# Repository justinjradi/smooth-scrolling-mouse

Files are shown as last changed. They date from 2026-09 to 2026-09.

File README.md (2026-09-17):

# Smooth Scrolling Mouse

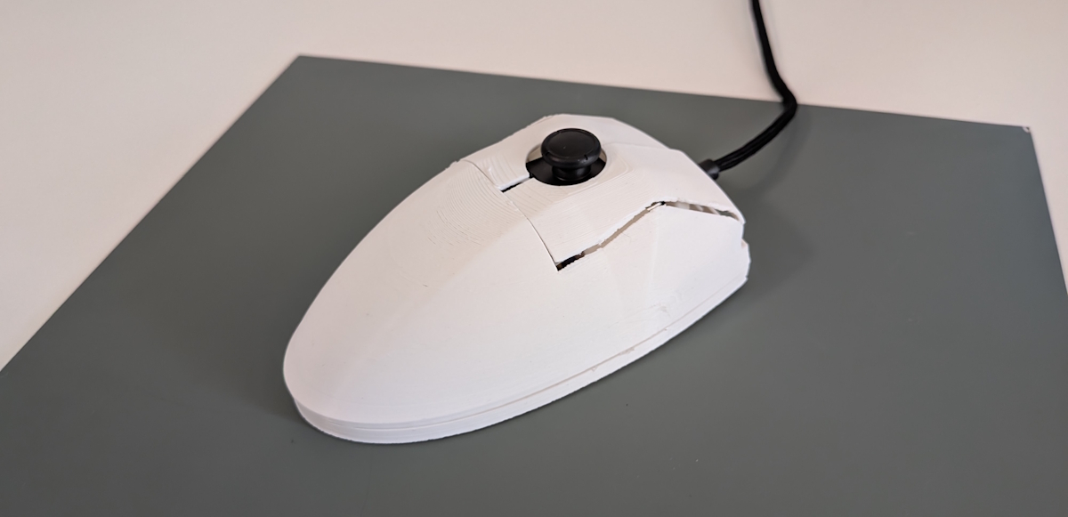
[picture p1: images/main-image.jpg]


### Overview

In this project, I built a a new type of USB computer mouse capable of scrolling and panning smoothly in any direction. The scroll wheel is replaced with a finger-operated joystick, which is held static during usage instead of being constantly when navigating large documents and workspaces.

Firmware was developed for a STM32 development board, involving writing custom USB device applications, a driver for a PMW3610 optical sensor, and reverse-engineering the requirements of Windows hosts using protocol knowledge and Wireshark. Furthermore, a chassis with clicking mechanism was designed using Autodesk Fusion and fabricated using an FDM 3D printer.

### System Design

The system was designed using a [WeAct STM32F411CEU6 development board](https://stm32-base.org/boards/STM32F411CEU6-WeAct-Black-Pill-V2.0.html), chosen for its small size, user USB connector, and USB FS peripheral supported by TinyUSB. A simple breakout board-based system architecture was used given that this was a quick prototype without large SI constraints.

The MCU development board was soldered onto perfboard along with Kailh silent mouse switches, pull-down resistors, and pin headers to form a mainboard. A PMW3610-DM optical mouse sensor breakout board was used for cursor tracking. Lastly, scrolling was implemented using a joystick.

A replacement joystick for the Nintendo switch and which was chosen to control scrolling/panning because of its small size, low force required to displace, and built-in button. Additionally, an FPC connector breakout board was used to interface with it.

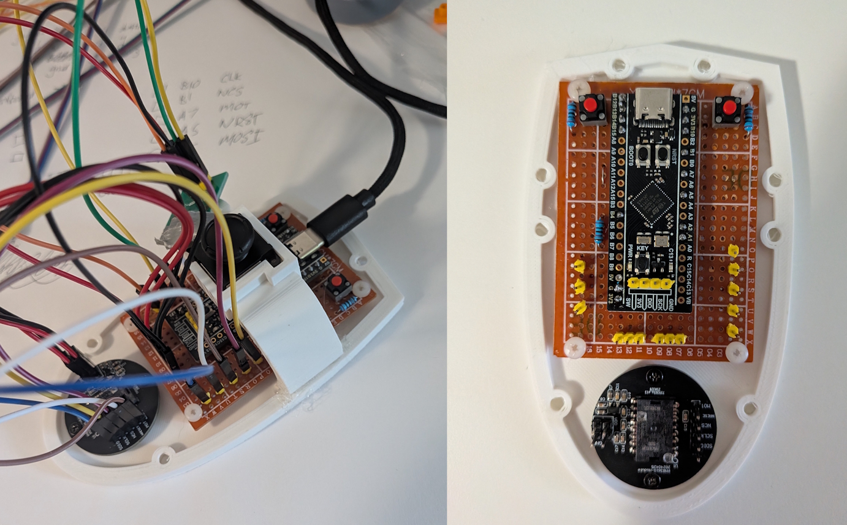
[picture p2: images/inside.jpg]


### Firmware Development

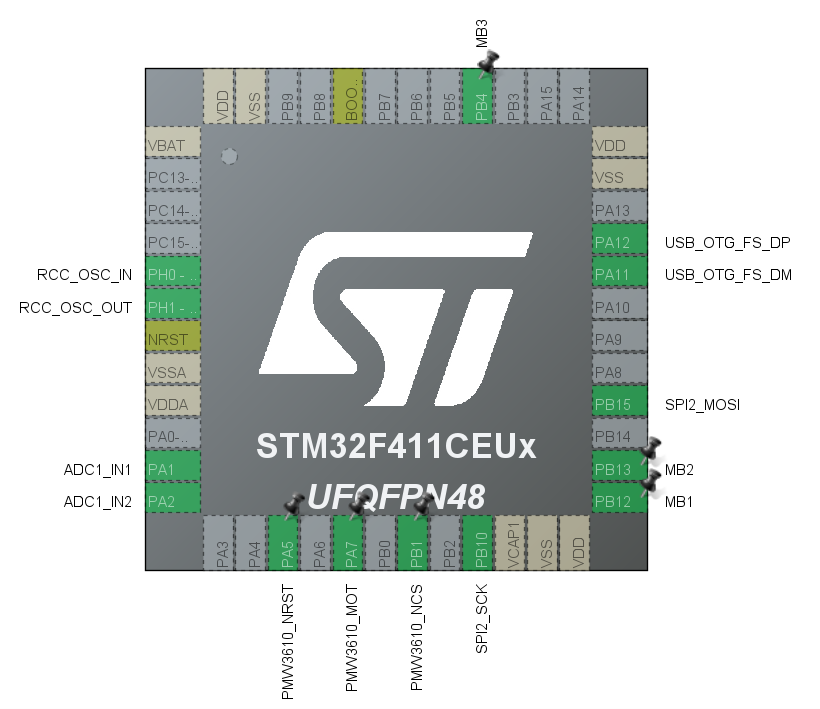
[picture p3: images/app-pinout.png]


#### Main Program

The main loop is structured as a single non-blocking cycle with one deliberate blocking point: a fixed 10-ms minimum loop time enforced right before the report is sent, which keeps the report rate steady regardless of how long sensor polling and other input handling take. At the top of every iteration, a timestamp is taken and the report's `x` and `y` fields are cleared, since these are relative values that should default to zero unless new motion is detected that iteration (unlike the buttons, which reflect a continuous state).

Pseudocode of the main program loop follows:

```pseudocode
loop:
    timestamp = now()
    report.x = 0
    report.y = 0

    tud_task()                      // service USB stack

    if MOT_pin is asserted:
        read burst motion data from PMW3610
        if valid:
            report.x = convert(delta_x)
            report.y = convert(delta_y)

    report.left_button   = !MB1_pin
    report.right_button  = !MB2_pin
    report.middle_button = !MB3_pin

    start ADC conversion (channel 1)
    report.scroll = convert(adc_value)

    start ADC conversion (channel 2)
    report.pan = convert(adc_value)
    stop ADC

    wait until (now() - timestamp) >= 10ms
    send report
```

The optical sensor is polled and the `MOT` pin is just read as a plain GPIO input each iteration. Updates to mouse buttons, however, are implemented using interrupts.

The joystick's two axes go through ADC1, configured for two channels in discontinuous conversion mode with a single conversion per trigger (`NbrOfDiscConversion = 1`). Rather than firing off both channels back-to-back in scan mode, each `HAL_ADC_Start()`/`HAL_ADC_PollForConversion()` call advances the sequencer by exactly one channel, so the two axes can be read as two distinct, independently-timed conversions within the loop. No DMA is used as polling was sufficiently fast at this conversion rate.

With respect to clock configuration, SYSCLK is set to 16 MHz and PLL M/N/Q dividers were chosen to provide exactly 48 MHz to the USB OTG peripheral.

#### PMW3610 Driver

A driver for the PMW3610 optical sensor is implemented in `inc/pmw3610.h`. The PMW3610 communicates over a 3-wire SPI-like interface, so SPI2 is configured half-duplex, `SPI_DIRECTION_1LINE`, meaning MOSI and MISO share a single physical line and the peripheral is manually switched between transmit and receive around each register access. It's set to Mode 0 (`CLKPolarity = LOW`, `CLKPhase = 1EDGE`) and a baud rate of 31.25 kbit. For simplicity, chip-select is implemented with GPIO calls.

Every register access follows the same two-phase pattern: select the chip, send a one-byte header with the MSB indicating read (0) or write (1) and the lower 7 bits as the register address, then either transmit or receive the data byte(s), and deselect. A read looks like this:

```c
HAL_GPIO_WritePin(dev_p->NCS_port_p, dev_p->NCS_pin, NCS_SELECT);

uint8_t first_byte[1] = {address & 0b01111111};  // MSB = 0: read operation
result = HAL_SPI_Transmit(dev_p->hspi_p, first_byte, 1, SPI_DEFAULT_TIMEOUT);

result = HAL_SPI_Receive(dev_p->hspi_p, data_p, size, SPI_DEFAULT_TIMEOUT);

HAL_GPIO_WritePin(dev_p->NCS_port_p, dev_p->NCS_pin, NCS_DESELECT);
```

Writes follow a similar process, sending the address with the MSB set to 1 followed by the value byte. `write_reg()` additionally wraps this in a clock-enable/disable sequence (writing specific values to the sensor's clock control register before and after) since the datasheet requires the sensor's internal SPI clock to be explicitly turned on before a write and off afterward.

`pmw3610_init()` runs through the sensor's documented startup sequence: power the sensor up from shutdown, clear the observation register, then read it back and check that the lower four bits read `1111` as the datasheet specifies (this confirms the sensor booted correctly). It then reads the product ID register and checks it against the expected value for the PMW3610, and finally writes a small set of performance/downshift registers to their recommended initial values.

`pmw3610_get_values()` does a single 4-byte burst read starting at the burst register, which returns the motion status byte plus the low bytes of X and Y and a shared high-nibble byte. If the motion bit isn't set, there's no new data and the function returns early with `valid = PMW3610_MOT_REG_INVAL`. Otherwise, the delta values need to be reconstructed: X and Y are each 12-bit signed integers, but the sensor packs their high 4 bits together into a single byte (upper nibble for X, lower nibble for Y) alongside their separate low bytes. The driver shifts each nibble into position, ORs it together with the corresponding low byte to get a 12-bit value, then manually sign-extends from bit 11 up through bit 15 before casting to `int16_t`.

#### USB Device Application

While other software methods as well as other firmware methods were evaluated (such as by emulating a Windows Precision touchpad; [repository link here](https://github.com/justinjradi/stm32-usb-touchpad)), I decided to use the specification for HID smooth scrolling mice on Windows defined in [wheel.docx (43.4 KiB)](https://download.microsoft.com/download/b/d/1/bd1f7ef4-7d72-419e-bc5c-9f79ad7bb66e/wheel.docx) in my latest prototype.

TinyUSB (version 0.17.0), was used to implement the HID-class USB device and is configured in `inc/tusb_config.h` for USB FS. The HID report descriptors that are used to implement the host's requirements for a HID smooth scrolling mouse follow. They are contained in `src/usb_descriptors.c`:

```c
uint8_t const desc_hid_report[] =
{
	0x05, 0x01,        // Usage Page (Generic Desktop Ctrls)
	0x09, 0x02,        // Usage (Mouse)
	0xA1, 0x01,        // Collection (Application)
	0x05, 0x01,        //   Usage Page (Generic Desktop Ctrls)
	0x09, 0x02,        //   Usage (Mouse)
	0xA1, 0x02,        //   Collection (Logical)
	0x85, REPORTID_MOUSE,  //     Report ID (REPORTID_MOUSE)
	0x09, 0x01,        //     Usage (Pointer)
	0xA1, 0x00,        //     Collection (Physical)
	0x05, 0x09,        //       Usage Page (Button)
	0x19, 0x01,        //       Usage Minimum (0x01)
	0x29, 0x05,        //       Usage Maximum (0x05)
	0x15, 0x00,        //       Logical Minimum (0)
	0x25, 0x01,        //       Logical Maximum (1)
	0x95, 0x05,        //       Report Count (5)
	0x75, 0x01,        //       Report Size (1)
	0x81, 0x02,        //       Input (Data,Var,Abs)
	0x95, 0x01,        //       Report Count (1)
	0x75, 0x03,        //       Report Size (3)
	0x81, 0x01,        //       Input (Const,Array,Abs)      -- 3-bit padding after 5 buttons
	0x05, 0x01,        //       Usage Page (Generic Desktop Ctrls)
	0x09, 0x30,        //       Usage (X)
	0x09, 0x31,        //       Usage (Y)
	0x95, 0x02,        //       Report Count (2)
	0x75, 0x08,        //       Report Size (8)
	0x15, 0x81,        //       Logical Minimum (-127)
	0x25, 0x7f,        //       Logical Maximum (127)
	0x81, 0x06,        //       Input (Data,Var,Rel)
	0xA1, 0x02,        //       Collection (Logical)
	0x85, REPORTID_RES_MULTIPLIER, //  Report ID (REPORTID_RES_MULTIPLIER)
	0x09, 0x48,        //         Usage (Resolution Multiplier)
	0x95, 0x01,        //         Report Count (1)
	0x75, 0x02,        //         Report Size (2)
	0x15, 0x00,        //         Logical Minimum (0)
	0x25, 0x01,        //         Logical Maximum (1)
	0x35, 0x01,        //         Physical Minimum (1)
	0x45, MAX_SCROLL_RES,   //     Physical Maximum (MAX_SCROLL_RES)
	0xB1, 0x02,        //         Feature (Data,Var,Abs,Non-volatile)
	0x85, REPORTID_MOUSE,  //     Report ID (REPORTID_MOUSE)
	0x09, 0x38,        //         Usage (Wheel)
	0x35, 0x00,        //         Physical Minimum (0)
	0x45, 0x00,        //         Physical Maximum (0)
	0x95, 0x01,        //         Report Count (1)
	0x75, 0x08,        //         Report Size (8)
	0x15, 0x81,        //         Logical Minimum (-127)
	0x25, 0x7f,        //         Logical Maximum (127)
	0x81, 0x06,        //         Input (Data,Var,Rel)
	0xC0,              //       End Collection
	0xA1, 0x02,        //       Collection (Logical)
	0x85, REPORTID_RES_MULTIPLIER, //  Report ID (REPORTID_RES_MULTIPLIER)
	0x09, 0x48,        //         Usage (0x48)
	0x95, 0x01,        //         Report Count (1)
	0x75, 0x02,        //         Report Size (2)
	0x15, 0x00,        //         Logical Minimum (0)
	0x25, 0x01,        //         Logical Maximum (1)
	0x35, 0x01,        //         Physical Minimum (1)
	0x45, MAX_PAN_RES,      //     Physical Maximum (MAX_PAN_RES)
	0xB1, 0x02,        //         Feature (Data,Var,Abs,Non-volatile)
	0x35, 0x00,        //         Physical Minimum (0)
	0x45, 0x00,        //         Physical Maximum (0)
	0x75, 0x04,        //         Report Size (4)
	0xB1, 0x01,        //         Feature (Const,Array,Abs,Non-volatile)  -- padding
	0x85, 0x01,        //         Report ID (1)
	0x05, 0x0C,        //         Usage Page (Consumer)
	0x0A, 0x38, 0x02,  //         Usage (AC Pan)
	0x95, 0x01,        //         Report Count (1)
	0x75, 0x08,        //         Report Size (8)
	0x15, 0x81,        //         Logical Minimum (-127)
	0x25, 0x7f,        //         Logical Maximum (127)
	0x81, 0x06,        //         Input (Data,Var,Rel)
	0xC0,              //       End Collection
	0xC0,              //     End Collection
	0xC0,              //   End Collection
	0xC0               // End Collection
};
```

The descriptor nests two logical collections inside the mouse's physical collection: one for scrolling and one for panning. The implementation of a library for the device application is contained in `inc/evcm.h` and it defines the following structs for reports:

```c
// Mouse Input Report
typedef struct __attribute__((packed))
{
	uint8_t left_button : 1;
	uint8_t right_button : 1;
	uint8_t middle_button : 1;
	uint8_t back_button : 1;
	uint8_t forward_button : 1;
	uint8_t padding : 3;
	int8_t x;
	int8_t y;
	int8_t scroll;
	int8_t pan;
} MouseReport;

// Resolution Multiplier Feature Report
typedef struct __attribute__((packed))
{
	uint8_t supports_scroll_res : 2;
	uint8_t supports_pan_res : 2;
	uint8_t padding : 4;
} ResMultiplierReport;
```

The mouse input report is sent from the device to host using the `tud_hid_report()` function whenever the function `evcm_send_mouse_report()` is called from the main loop.

To handle the resolution multiplier feature report being sent from the host to device, the following line is added to the `tud_hid_set_report_cb()` callback:

```c
tud_hid_report(0, buffer, bufsize);
```

Additionally, the resolution multiplier feature report is sent to the host whenever it requests it. This was not well-documented and discovered by analyzing USB traffic. Furthermore, TinyUSB didn't support a method for users of the library to implement device-to-host feature reporting at the time, so I modified `hidd_control_xfer_cb()` in `tinyusb/src/class/hid/hid_device.c` of the source code to implement this. A snippet from the function showing the modification is shown:

```c
case HID_REQ_CONTROL_GET_REPORT:
  if (stage == CONTROL_STAGE_SETUP) {
    uint8_t const report_type = tu_u16_high(request->wValue);
    uint8_t const report_id = tu_u16_low(request->wValue);

    uint8_t *report_buf = p_hid->ctrl_buf;
    uint16_t req_len = tu_min16(request->wLength, CFG_TUD_HID_EP_BUFSIZE);

    uint16_t xferlen = 0;

    // If host request a specific Report ID, add ID to as 1 byte of response
    if ((report_id != HID_REPORT_TYPE_INVALID) && (req_len > 1)) {
      *report_buf++ = report_id;
      req_len--;

      xferlen++;

      /*
       * Respond to get_report over endpoint 0
       */
      if (report_id == REPORTID_RES_MULTIPLIER)
      {
        *report_buf++ = 0x05;  // Data byte
        xferlen++;
      }
      /*
       *
       */
    }

    xferlen += tud_hid_get_report_cb(hid_itf, report_id, (hid_report_type_t)report_type, report_buf, req_len);
    TU_ASSERT(xferlen > 0);

    tud_control_xfer(rhport, request, p_hid->ctrl_buf, xferlen);
  }
  break;
```

### Chassis Design

A chassis was designed in Autodesk Fusion, including a base plate and bracket to hold the joystick (seen in pictures in System Design section), and a shell. A cross section of the mechanism for pressing the mainboard buttons, which was part of the shell, is shown below. Models for the mainboard and optical sensor breakout board were also created to aid with space planning. The CAD file, `mouse-body-v115.f3z` is available for download.

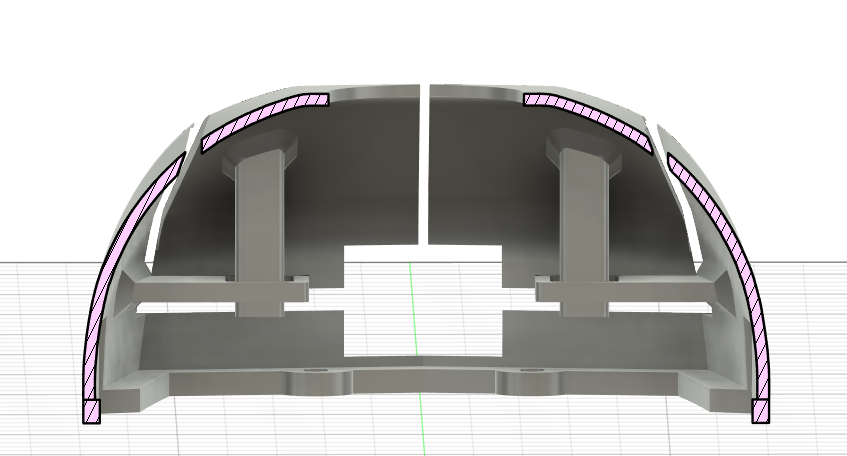
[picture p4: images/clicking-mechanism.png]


### Next Steps

While I consider this current prototype to be complete, I'm still exploring hardware and software approaches to improving the amount of control that the mouse gives over viewport navigation. For example, one thing that I've spent some time working on is custom joystick and scroll ball designs to improve the range of motion. Some things that were involved in these explorations included :

- Performing calculations to calculate the amount of torque required to displace a joystick compensated by tension springs, given their dimensions and spring constants.
- Taking advantage of my access to student FEA software and using Ansys Mechanical to determine the force required to displace a compliant rod. In addition to using parameters from datasheets, this involved creating a model for the elastomer based on technical literature.
- Similarly, I also used Ansys Maxwell to perform a parametric magnetostatic simulation to find the minimum magnetic flux density seen by a Hall Effect Sensor given the possible positions of a magnet. This helped me to verify whether a particular design was feasible given the sensing range of the Hall Effect sensor and its distance from the magnet. A graph produced in this analysis is pictured below.

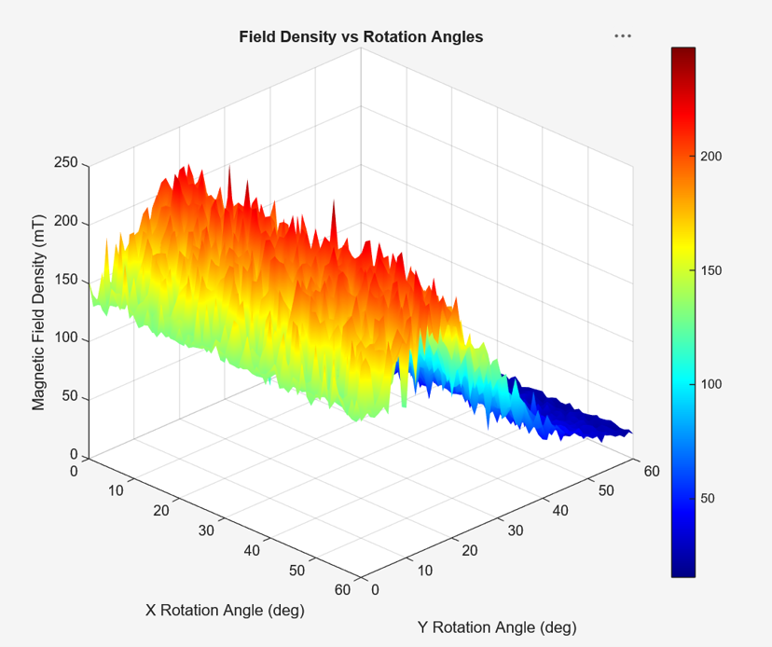
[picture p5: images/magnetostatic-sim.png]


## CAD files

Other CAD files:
mouse-body-v115.f3z

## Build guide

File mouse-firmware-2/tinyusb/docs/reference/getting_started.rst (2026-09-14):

***************
Getting Started
***************

Add TinyUSB to your project
---------------------------

It is relatively simple to incorporate tinyusb to your project

* Copy or ``git submodule`` this repo into your project in a subfolder. Let's say it is *your_project/tinyusb*
* Add all the .c in the ``tinyusb/src`` folder to your project
* Add *your_project/tinyusb/src* to your include path. Also make sure your current include path also contains the configuration file tusb_config.h.
* Make sure all required macros are all defined properly in tusb_config.h (configure file in demo application is sufficient, but you need to add a few more such as CFG_TUSB_MCU, CFG_TUSB_OS since they are passed by IDE/compiler to maintain a unique configure for all boards).
* If you use the device stack, make sure you have created/modified usb descriptors for your own need. Ultimately you need to implement all **tud descriptor** callbacks for the stack to work.
* Add tusb_init() call to your reset initialization code.
* Call ``tud_int_handler()`` (device) and/or ``tuh_int_handler()`` (host) in your USB IRQ Handler
* Implement all enabled classes's callbacks.
* If you don't use any RTOSes at all, you need to continuously and/or periodically call tud_task()/tuh_task() function. All of the callbacks and functionality are handled and invoked within the call of that task runner.

.. code-block::

   int main(void)
   {
     your_init_code();
     tusb_init(); // initialize tinyusb stack

     while(1) // the mainloop
     {
       your_application_code();

       tud_task(); // device task
       tuh_task(); // host task
     }
   }

Examples
--------

For your convenience, TinyUSB contains a handful of examples for both host and device with/without RTOS to quickly test the functionality as well as demonstrate how API() should be used. Most examples will work on most of `the supported boards <supported.rst>`_. Firstly we need to ``git clone`` if not already

.. code-block::

   $ git clone https://github.com/hathach/tinyusb tinyusb
   $ cd tinyusb

Some ports will also require a port-specific SDK (e.g. RP2040) or binary (e.g. Sony Spresense) to build examples. They are out of scope for tinyusb, you should download/install it first according to its manufacturer guide.

Dependencies
^^^^^^^^^^^^

The hardware code is located in ``hw/bsp`` folder, and is organized by family/boards. e.g raspberry_pi_pico is located in ``hw/bsp/rp2040/boards/raspberry_pi_pico`` where FAMILY=rp2040 and BOARD=raspberry_pi_pico. Before building, we firstly need to download dependencies such as: MCU low-level peripheral driver and external libraries e.g FreeRTOS (required by some examples). We can do that by either ways:

1. Run ``tools/get_deps.py {FAMILY}`` script to download all dependencies for a family as follow. Note: For TinyUSB developer to download all dependencies, use FAMILY=all.

.. code-block::

   $ python tools/get_deps.py rp2040

2. Or run the ``get-deps`` target in one of the example folder as follow.

.. code-block::

   $ cd examples/device/cdc_msc
   $ make BOARD=raspberry_pi_pico get-deps

You only need to do this once per family. Check out `complete list of dependencies and their designated path here <dependencies.rst>`_

Build
^^^^^

To build example, first change directory to an example folder.

.. code-block::

   $ cd examples/device/cdc_msc

Then compile with ``make BOARD={board_name} all`` , for example

.. code-block::

   $ make BOARD=raspberry_pi_pico all

Note: some examples especially those that uses Vendor class (e.g webUSB) may requires udev permission on Linux (and/or macOS) to access usb device. It depends on your OS distro, typically copy ``99-tinyusb.rules`` and reload your udev is good to go

.. code-block::

   $ cp examples/device/99-tinyusb.rules /etc/udev/rules.d/
   $ sudo udevadm control --reload-rules && sudo udevadm trigger

RootHub Port Selection
~~~~~~~~~~~~~~~~~~~~~~

If a board has several ports, one port is chosen by default in the individual board.mk file. Use option ``PORT=x`` To choose another port. For example to select the HS port of a STM32F746Disco board, use:

.. code-block::

   $ make BOARD=stm32f746disco PORT=1 all

Port Speed
~~~~~~~~~~

A MCU can support multiple operational speed. By default, the example build system will use the fastest supported on the board. Use option ``SPEED=full/high`` e.g To force F723 operate at full instead of default high speed

.. code-block::

   $ make BOARD=stm32f746disco SPEED=full all

Size Analysis
~~~~~~~~~~~~~

First install `linkermap tool <https://github.com/hathach/linkermap>`_ then ``linkermap`` target can be used to analyze code size. You may want to compile with ``NO_LTO=1`` since -flto merges code across .o files and make it difficult to analyze.

.. code-block::

   $ make BOARD=feather_nrf52840_express NO_LTO=1 all linkermap

Debug
^^^^^

To compile for debugging add ``DEBUG=1``\ , for example

.. code-block::

   $ make BOARD=feather_nrf52840_express DEBUG=1 all

Log
~~~

Should you have an issue running example and/or submitting an bug report. You could enable TinyUSB built-in debug logging with optional ``LOG=``. LOG=1 will only print out error message, LOG=2 print more information with on-going events. LOG=3 or higher is not used yet.

.. code-block::

   $ make BOARD=feather_nrf52840_express LOG=2 all

Logger
~~~~~~

By default log message is printed via on-board UART which is slow and take lots of CPU time comparing to USB speed. If your board support on-board/external debugger, it would be more efficient to use it for logging. There are 2 protocols:

* `LOGGER=rtt`: use `Segger RTT protocol <https://www.segger.com/products/debug-probes/j-link/technology/about-real-time-transfer/>`_

  * Cons: requires jlink as the debugger.
  * Pros: work with most if not all MCUs
  * Software viewer is JLink RTT Viewer/Client/Logger which is bundled with JLink driver package.

* ``LOGGER=swo``\ : Use dedicated SWO pin of ARM Cortex SWD debug header.

  * Cons: only work with ARM Cortex MCUs minus M0
  * Pros: should be compatible with more debugger that support SWO.
  * Software viewer should be provided along with your debugger driver.

.. code-block::

   $ make BOARD=feather_nrf52840_express LOG=2 LOGGER=rtt all
   $ make BOARD=feather_nrf52840_express LOG=2 LOGGER=swo all

Flash
^^^^^

``flash`` target will use the default on-board debugger (jlink/cmsisdap/stlink/dfu) to flash the binary, please install those support software in advance. Some board use bootloader/DFU via serial which is required to pass to make command

.. code-block::

   $ make BOARD=feather_nrf52840_express flash
   $ make SERIAL=/dev/ttyACM0 BOARD=feather_nrf52840_express flash

Since jlink can be used with most of the boards, there is also ``flash-jlink`` target for your convenience.

.. code-block::

   $ make BOARD=feather_nrf52840_express flash-jlink

Some board use uf2 bootloader for drag & drop in to mass storage device, uf2 can be generated with ``uf2`` target

.. code-block::

   $ make BOARD=feather_nrf52840_express all uf2

IAR Support
-----------

Use project connection
^^^^^^^^^^^^^^^^^^^^^^

IAR Project Connection files are provided to import TinyUSB stack into your project.

* A buldable project of your MCU need to be created in advance.

  * Take example of STM32F0:

    -  You need `stm32l0xx.h`, `startup_stm32f0xx.s`, `system_stm32f0xx.c`.

    - `STM32L0xx_HAL_Driver` is only needed to run examples, TinyUSB stack itself doesn't rely on MCU's SDKs.

* Open ``Tools -> Configure Custom Argument Variables`` (Switch to `Global` tab if you want to do it for all your projects)
   Click `New Group ...`, name it to `TUSB`, Click `Add Variable ...`, name it to `TUSB_DIR`, change it's value to the path of your TinyUSB stack,
   for example `C:\\tinyusb`

Import stack only
~~~~~~~~~~~~~~~~~

1. Open ``Project -> Add project Connection ...``, click `OK`, choose `tinyusb\\tools\\iar_template.ipcf`.

Run examples
~~~~~~~~~~~~

1. (Python3 is needed) Run ``iar_gen.py`` to generate .ipcf files of examples:

   .. code-block::

     cd C:\tinyusb\tools
     python iar_gen.py

2. Open `Project -> Add project Connection ...`, click `OK`, choose `tinyusb\\examples\\(.ipcf of example)`.
   For example `C:\\tinyusb\\examples\\device\\cdc_msc\\iar_cdc_msc.ipcf`

Native CMake support (9.50.1+)
^^^^^^^^^^^^^^^^^^^^^^^^^^^^^^

With 9.50.1 release, IAR added experimental native CMake support (strangely not mentioned in public release note). Now it's possible to import CMakeLists.txt then build and debug as a normal project.

Following these steps:

1. Add IAR compiler binary path to system ``PATH`` environment variable, such as ``C:\Program Files\IAR Systems\Embedded Workbench 9.2\arm\bin``.
2. Create new project in IAR, in Tool chain dropdown menu, choose CMake for Arm then Import ``CMakeLists.txt`` from chosen example directory.
3. Set up board option in ``Option - CMake/CMSIS-TOOLBOX - CMake``, for example :code:`-DBOARD=stm32f439nucleo -DTOOLCHAIN=iar`, **Uncheck 'Override tools in env'**.
4. (For debug only) Choose correct CPU model in ``Option - General Options - Target``, to profit register and memory view.

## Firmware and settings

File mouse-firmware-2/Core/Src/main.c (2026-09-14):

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
/* Includes ------------------------------------------------------------------*/
#include "main.h"

/* USER CODE BEGIN Includes */
#include "tusb.h"
#include "evcm.h"
#include "delay.h"
#include "pmw3610.h"
/* USER CODE END Includes */

ADC_HandleTypeDef hadc1;

SPI_HandleTypeDef hspi2;

PCD_HandleTypeDef hpcd_USB_OTG_FS;

/* USER CODE BEGIN PV */
MouseReport mouseReport = {0};
uint8_t update_required = 0;
uint32_t timestamp;
struct pmw3610_dev pmw3610;
struct pmw3610_values vals = {0};
/* USER CODE END PV */

void SystemClock_Config(void);
static void MX_GPIO_Init(void);
static void MX_USB_OTG_FS_PCD_Init(void);
static void MX_ADC1_Init(void);
static void MX_SPI2_Init(void);
/* USER CODE BEGIN PFP */
int8_t conv_delta_x(int16_t pmw3610_val);
int8_t conv_delta_y(int16_t pmw3610_val);
int8_t conv_scroll_data(uint32_t adc_value);
int8_t conv_pan_data(uint32_t adc_value);
/* USER CODE END PFP */

/**
  * @brief  The application entry point.
  * @retval int
  */
int main(void)
{

  /* MCU Configuration--------------------------------------------------------*/

  /* Reset of all peripherals, Initializes the Flash interface and the Systick. */
  HAL_Init();

  /* Configure the system clock */
  SystemClock_Config();

  /* Initialize all configured peripherals */
  MX_GPIO_Init();
  MX_USB_OTG_FS_PCD_Init();
  MX_ADC1_Init();
  MX_SPI2_Init();
  /* USER CODE BEGIN 2 */

  // Initialize delay functions
  delay_init();

  // Initialize pmw3610
	pmw3610.hspi_p = &hspi2;
	pmw3610.NCS_port_p = PMW3610_NCS_GPIO_Port;
	pmw3610.NCS_pin = PMW3610_NCS_Pin;
  HAL_GPIO_WritePin(PMW3610_NRST_GPIO_Port, PMW3610_NRST_Pin, PMW3610_NRST_SET);
  delay_ms(200);
  HAL_GPIO_WritePin(PMW3610_NRST_GPIO_Port, PMW3610_NRST_Pin, PMW3610_NRST_RESET);
  delay_ms(200);
  HAL_GPIO_WritePin(PMW3610_NRST_GPIO_Port, PMW3610_NRST_Pin, PMW3610_NRST_SET);
  delay_ms(200);
  HAL_StatusTypeDef pmw3610_result = pmw3610_init(&pmw3610);
  if (pmw3610_result != HAL_OK)
  {
  	__NOP();
  }
  __NOP();

  // Initialize tinyUSB
  tud_init(BOARD_TUD_RHPORT);

  /* USER CODE END 2 */

  /* Infinite loop */
  /* USER CODE BEGIN WHILE */
  while (1)
  {

  	// Reset loop values
  	timestamp = HAL_GetTick();
  	mouseReport.x = 0;
  	mouseReport.y = 0;

  	// Run TinyUSB task
  	tud_task();

  	//  Get cursor position data from optical sensor
  	if (HAL_GPIO_ReadPin(PMW3610_MOT_GPIO_Port, PMW3610_MOT_Pin) == PMW3610_MOT_PIN_SET)
  	{
  		pmw3610_result = pmw3610_get_values(&pmw3610, &vals);
  		if (pmw3610_result != HAL_OK)
  		{
  			__NOP();
  		}
  		else if (vals.valid == PMW3610_MOT_REG_INVAL)
  		{
  			__NOP();
  		}
  		else
  		{
  			mouseReport.x = conv_delta_x(vals.delta_x);
  			mouseReport.y = conv_delta_y(vals.delta_y);
  		}
  	}

  	// Get data from mouse buttons
  	mouseReport.left_button = HAL_GPIO_ReadPin(MB1_GPIO_Port, MB1_Pin) ^ 1;
  	mouseReport.right_button = HAL_GPIO_ReadPin(MB2_GPIO_Port, MB2_Pin) ^ 1;
  	mouseReport.middle_button = HAL_GPIO_ReadPin(MB3_GPIO_Port, MB3_Pin) ^ 1;

  	// Get scroll data
  	HAL_ADC_Start(&hadc1);
  	if (HAL_ADC_PollForConversion(&hadc1, 5) != HAL_OK)
  	{
  		Error_Handler();
  	}
  	mouseReport.scroll = conv_scroll_data(HAL_ADC_GetValue(&hadc1));

  	// Get pan data
  	HAL_ADC_Start(&hadc1);
  	if (HAL_ADC_PollForConversion(&hadc1, 5) != HAL_OK)
  	{
  		Error_Handler();
  	}
  	mouseReport.pan = conv_pan_data(HAL_ADC_GetValue(&hadc1));
  	HAL_ADC_Stop(&hadc1);	// ADC needs to be stopped after second conversion

  	// Send report
  	while (HAL_GetTick() - timestamp < 10);
  	evcm_send_mouse_report(mouseReport);

    /* USER CODE END WHILE */

    /* USER CODE BEGIN 3 */
  }
  /* USER CODE END 3 */
}

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
/* USER CODE BEGIN 4 */
// input: 12-bit signed value
int8_t conv_delta_x(int16_t pmw3610_val)
{
	int16_t tmp = (pmw3610_val / 2);
	if (tmp >= 127)
	{
		return 127;
	}
	else if (tmp <= -128)
	{
		return -128;
	}
	return (int8_t)tmp;
}

// input: 12-bit signed value
int8_t conv_delta_y(int16_t pmw3610_val)
{
	int16_t tmp = (pmw3610_val / 2);
	if (tmp >= 127)
	{
		return 127;
	}
	else if (tmp <= -128)
	{
		return -128;
	}
	return (int8_t)tmp;
}

// input: 8-bit unsigned value
int8_t conv_scroll_data(uint32_t adc_value)
{
	if (adc_value >= 180) return 30;
	if (adc_value >= 80) return 0;
	return -30;
}

// input: 8-bit unsigned value
int8_t conv_pan_data(uint32_t adc_value)
{
	if (adc_value >= 180) return 30;
	if (adc_value >= 80) return 0;
	return -30;
}

/* USER CODE END 4 */
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


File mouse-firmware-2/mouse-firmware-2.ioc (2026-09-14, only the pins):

Mcu.UserName=STM32F411CEUx
PA1.Signal=ADCx_IN1
PA11.Signal=USB_OTG_FS_DM
PA12.Signal=USB_OTG_FS_DP
PA2.Signal=ADCx_IN2
PA5.GPIO_Label=PMW3610_NRST
PA5.Signal=GPIO_Output
PA7.GPIO_Label=PMW3610_MOT
PA7.Signal=GPIO_Input
PB1.GPIO_Label=PMW3610_NCS
PB1.Signal=GPIO_Output
PB10.Signal=SPI2_SCK
PB12.GPIO_Label=MB1
PB12.Signal=GPIO_Input
PB13.GPIO_Label=MB2
PB13.Signal=GPIO_Input
PB15.Signal=SPI2_MOSI
PB4.GPIO_Label=MB3
PB4.Signal=GPIO_Input

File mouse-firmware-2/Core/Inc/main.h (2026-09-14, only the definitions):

#define PMW3610_NRST_Pin GPIO_PIN_5
#define PMW3610_NRST_GPIO_Port GPIOA
#define PMW3610_MOT_Pin GPIO_PIN_7
#define PMW3610_MOT_GPIO_Port GPIOA
#define PMW3610_NCS_Pin GPIO_PIN_1
#define PMW3610_NCS_GPIO_Port GPIOB
#define MB1_Pin GPIO_PIN_12
#define MB1_GPIO_Port GPIOB
#define MB2_Pin GPIO_PIN_13
#define MB2_GPIO_Port GPIOB
#define MB3_Pin GPIO_PIN_4
#define MB3_GPIO_Port GPIOB

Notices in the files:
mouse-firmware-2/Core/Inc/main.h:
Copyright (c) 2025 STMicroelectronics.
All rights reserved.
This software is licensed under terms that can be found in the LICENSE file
